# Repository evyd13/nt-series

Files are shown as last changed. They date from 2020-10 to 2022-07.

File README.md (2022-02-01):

# nt-series

## FC660C
Please see the controller for the FC660C [here](https://github.com/evyd13/fc660c-controller).

## About
Replacement PCBs for the FC660m, FC750r, FC980m and FC210TP.

Each of these PCBs have been tested by me, but I cannot guarantee that they work for you.

Use the latest nightly version of KiCAD to open these files. Gerbers and BOM are included for every PCB.

## Stabilizers
All of these PCB designs support PCB mounted stabilizers, but only with a custom made plate, as the stock plate tabs prevent you from putting the plate and PCB together with PCB mounted stabilizers installed.

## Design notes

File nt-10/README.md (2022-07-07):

# nt-10 daughterboard for Leopold keyboards

The nt-10 is a USB-C daughterboard designed to fit the Leopold range of keyboards.  
At the time of writing those are the:

- FC750r
- FC980m
- FC900r

## Installation

Upon removal of the old (probably Mini USB) daughterboard, carefully insert the nt-10 and make sure the USB-C connector fits the cutout in the case. If it does not fit, you can use a small file to increase the cutout size.

### Wiring

The wiring is as follows:

Wiring of nt-10 daughterboard for Leopold keyboard

You might have to swap the wires on some boards, I had to on the 980m. Lift up the tabs using tweezers or a small knife (don't hurt yourself!) and take out the wires, then press the tabs back down and insert the wires in the correct order.

## BOM

| LCSC part # | Description | Value | Package  | Amount |
| --- | --- | ----- | --- | ---:|
| C27834 | Resistor | 5.1k  | 0805 | 2 |
| C261942 | Fuse | | 0805 | 1 |
| C7519 | ESD prot. | | SOT32-6  | 1 |
| C165948 | USB-C conn. | | | 1 |
| C160404 | JST SH 1x4 | | | 1 |
| C392176 | PicoBlade 1x5 | | | 1 |

Use at your own risk.

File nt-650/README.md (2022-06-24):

# nt-650

This is a replacement controller PCB for the FC650M.

nt-650 PCB

## Revisions

### rev1
First revision

## BOM

| LCSC part # | Description | Value | Package  | Amount |
| --- | --- | ----- | --- | ---:|
| C14663 | Capacitor | 0.1uF | 0603 | 4 |
| C19666 | Capacitor | 4.7uF | 0603 | 1 |
| C15849 | Capacitor | 1uF | 0603 | 1 |
| C261942 | Fuse | | 0805 | 1 |
| C124360 | Pin header | 2x16  | TH | 1 |
| C25804 | Resistor | 10K | 0603 | 2 |
| C112161 | MCU | 32U4  | QFN-44 | 1 |
| C341521 | Resonator | 16MHz | SMD | 1 |
| C92584 | Switch | | SMD | 1 |

Use at your own risk.

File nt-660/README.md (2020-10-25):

# nt-660

This is a replacement PCB for the FC660m.

nt-660 PCB

## Revisions

### rev1.1
Adds FC660C bottom row (1.25u - 1.25u - 1.25u - 6u - ...)

### rev1.0
First revision

## BOM

| LCSC part # | Description | Value | Package  | Amount |
| --- | --- | ----- | --- | ---:|
| C128353 | Capacitor | 0.1uF | 0805 | 3 |
| C131056 | Capacitor | 4.7uF | 0805 | 1 |
| C215803 | Capacitor | 1uF | 0805 | 1 |
| C109001 | Diode | | 0805 | 68 |
| C261942 | Fuse | | 0805 | 1 |
| C145778 | Connector | | SMD/TH | 1 |
| C103904 | Resistor | 10K | 0805 | 2 |
| C384174 | Resistor | 1K | 0805 | 1 |
| C325772 | Resistor | 22 | 0805 | 2 |
| C44854 | MCU | 32U4  | QFP-44 | 1 |
| C341521 | Resonator | 16MHz | SMD | 1 |
| C7519 | ESD prot. | | SOT23-6  | 1 |
| C92584 | Switch | | SMD | 1 |

Use at your own risk.

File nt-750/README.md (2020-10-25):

# nt-750

This is a replacement PCB for the FC750r.

nt-750 PCB

## BOM

| LCSC part # | Description | Value | Package  | Amount |
| --- | --- | ----- | --- | ---:|
| C128353 | Capacitor | 0.1uF | 0805 | 4 |
| C131056 | Capacitor | 4.7uF | 0805 | 1 |
| C215803 | Capacitor | 1uF | 0805 | 1 |
| C109001 | Diode | | 0805 | 89 |
| C261942 | Fuse | | 0805 | 1 |
| C157923 | Connector | | TH | 1 |
| C103904 | Resistor | 10K | 0805 | 2 |
| C384174 | Resistor | 1K | 0805 | 1 |
| C325772 | Resistor | 22 | 0805 | 2 |
| C44854 | MCU | 32U4  | QFP-44 | 1 |
| C341521 | Resonator | 16MHz | SMD | 1 |
| C7519 | ESD prot. | | SOT23-6  | 1 |
| C92584 | Switch | | SMD | 1 |

Use at your own risk.

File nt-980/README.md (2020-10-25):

# nt-980

This is a replacement PCB for the FC980m.

nt-980 PCB

## BOM

| LCSC part # | Description | Value | Package  | Amount |
| --- | --- | ----- | --- | ---:|
| C128353 | Capacitor | 0.1uF | 0805 | 4 |
| C131056 | Capacitor | 4.7uF | 0805 | 1 |
| C215803 | Capacitor | 1uF | 0805 | 1 |
| C109001 | Diode | | 0805 | 100 |
| C261942 | Fuse | | 0805 | 1 |
| C64617 | Female header | | SMD | 1 |
| C103904 | Resistor | 10K | 0805 | 2 |
| C384174 | Resistor | 1K | 0805 | 3 |
| C325772 | Resistor | 22 | 0805 | 2 |
| C44854 | MCU | 32U4  | QFP-44 | 1 |
| C341521 | Resonator | 16MHz | SMD | 1 |
| C7519 | ESD prot. | | SOT23-6  | 1 |
| C92584 | Switch | | SMD | 1 |

Use at your own risk.

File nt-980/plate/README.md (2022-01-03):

Plate files for FC980m.  

**This CANNOT be used with the stock FC980m PCB!** (Stock PCB uses plate stabs)

The KLE files can be used with the Ai03 plate generator to get the proper cut out possition of the switches (the edge cuts would need to be manually added to the file): https://kbplate.ai03.com/

Note: Only confirmed Alternate ANSI Layout <alternateLayouts.ANSI.dxf>, the other layout files "should" work but use at your own risk.

Alternate Layout ANSI <alternateLayouts.ANSI.dxf>
AlternateLayout

Alternate Layout ANSI/ISO <alternateLayouts.ISO.dxf>
AlternateLayout

Standard Layout ANSI <standardLayout.ANSI.dxf>
StandardLayout

Standard Layout ISO <standardLayout.ISO.dxf>
StandardLayoutISO

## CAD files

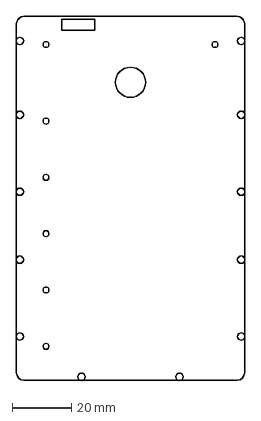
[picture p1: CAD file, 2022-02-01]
nt-210/pcb-outline.dxf
77.3 x 123.2 mm

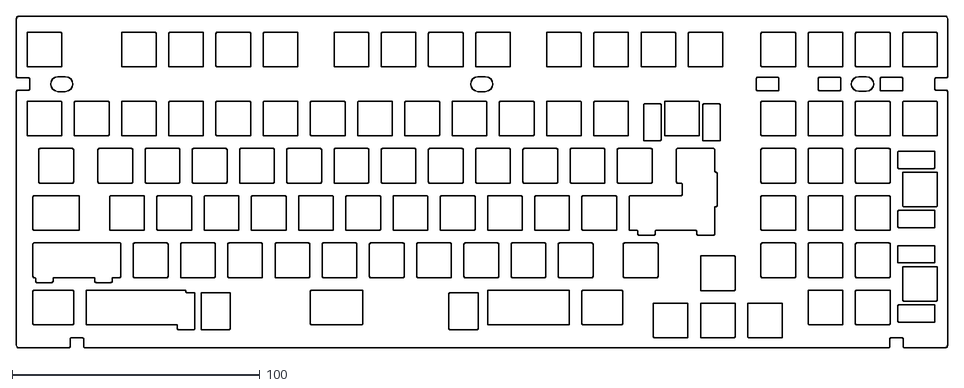
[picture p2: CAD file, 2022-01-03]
nt-980/plate/alternateLayouts.ISO.dxf
375.6 x 133.8

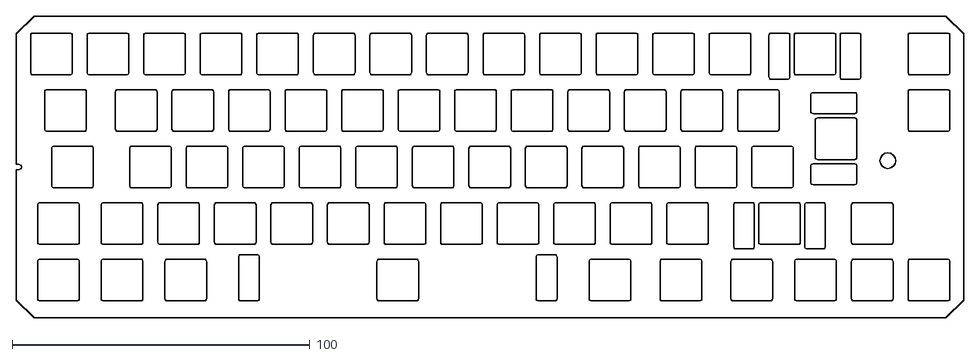
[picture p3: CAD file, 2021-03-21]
nt-660/plate/iso.dxf
318.5 x 101.4

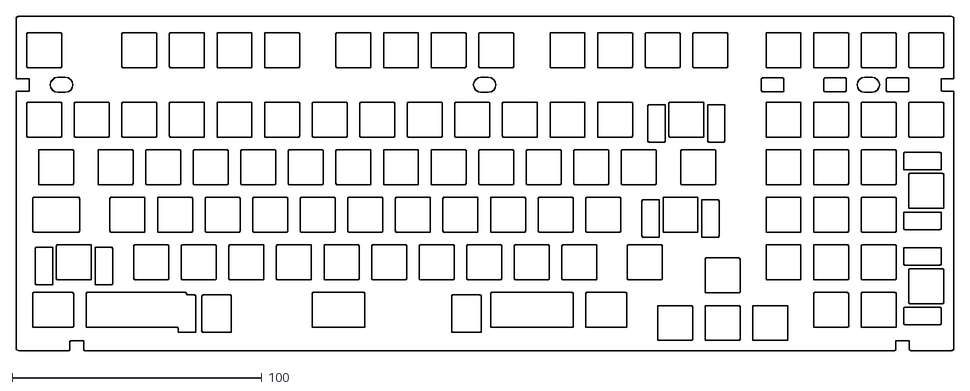
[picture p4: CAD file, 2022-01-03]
nt-980/plate/alternateLayouts.ANSI.dxf
375.6 x 133.8

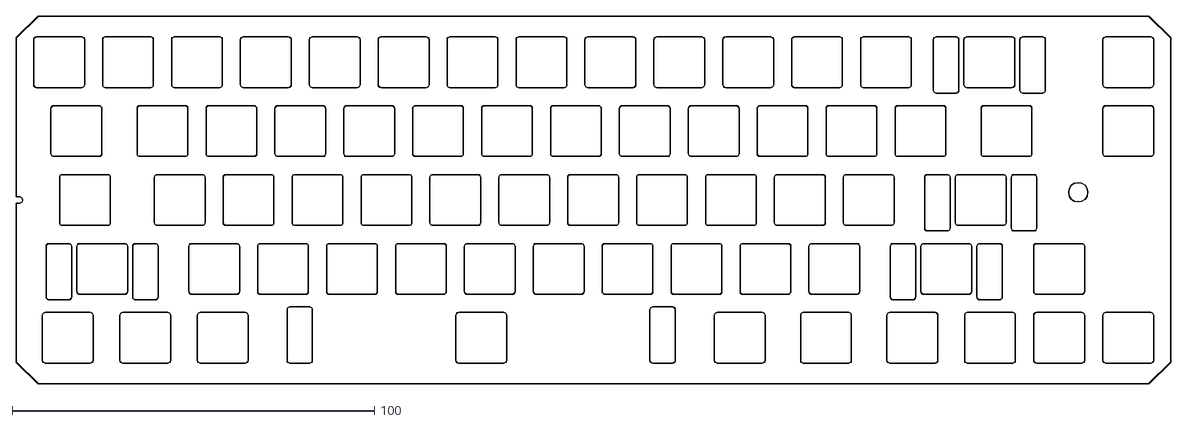
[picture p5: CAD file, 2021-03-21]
nt-660/plate/ansi.dxf
318.5 x 101.4

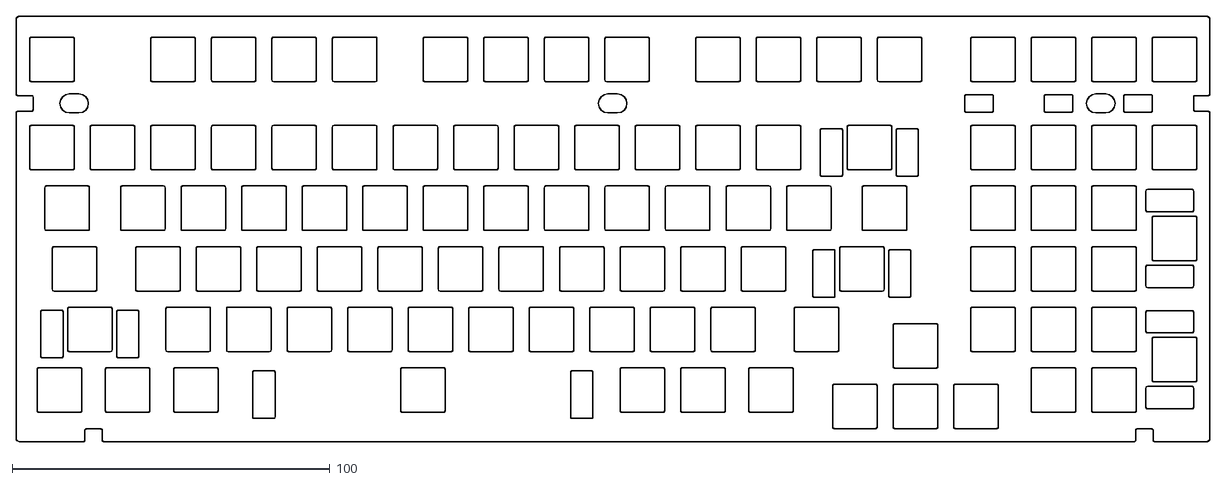
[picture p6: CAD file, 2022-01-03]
nt-980/plate/standardLayout.ANSI.dxf
375.6 x 133.8

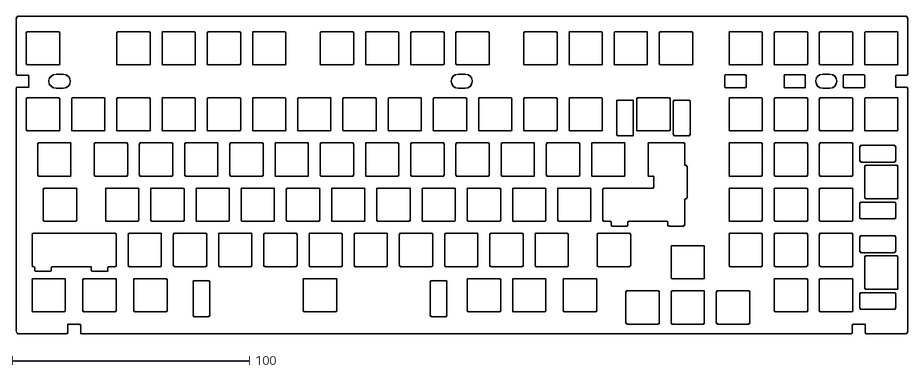
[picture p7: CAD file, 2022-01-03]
nt-980/plate/standardLayout.ISO.dxf
375.6 x 133.8

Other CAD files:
nt-660/plate/plate.FCStd

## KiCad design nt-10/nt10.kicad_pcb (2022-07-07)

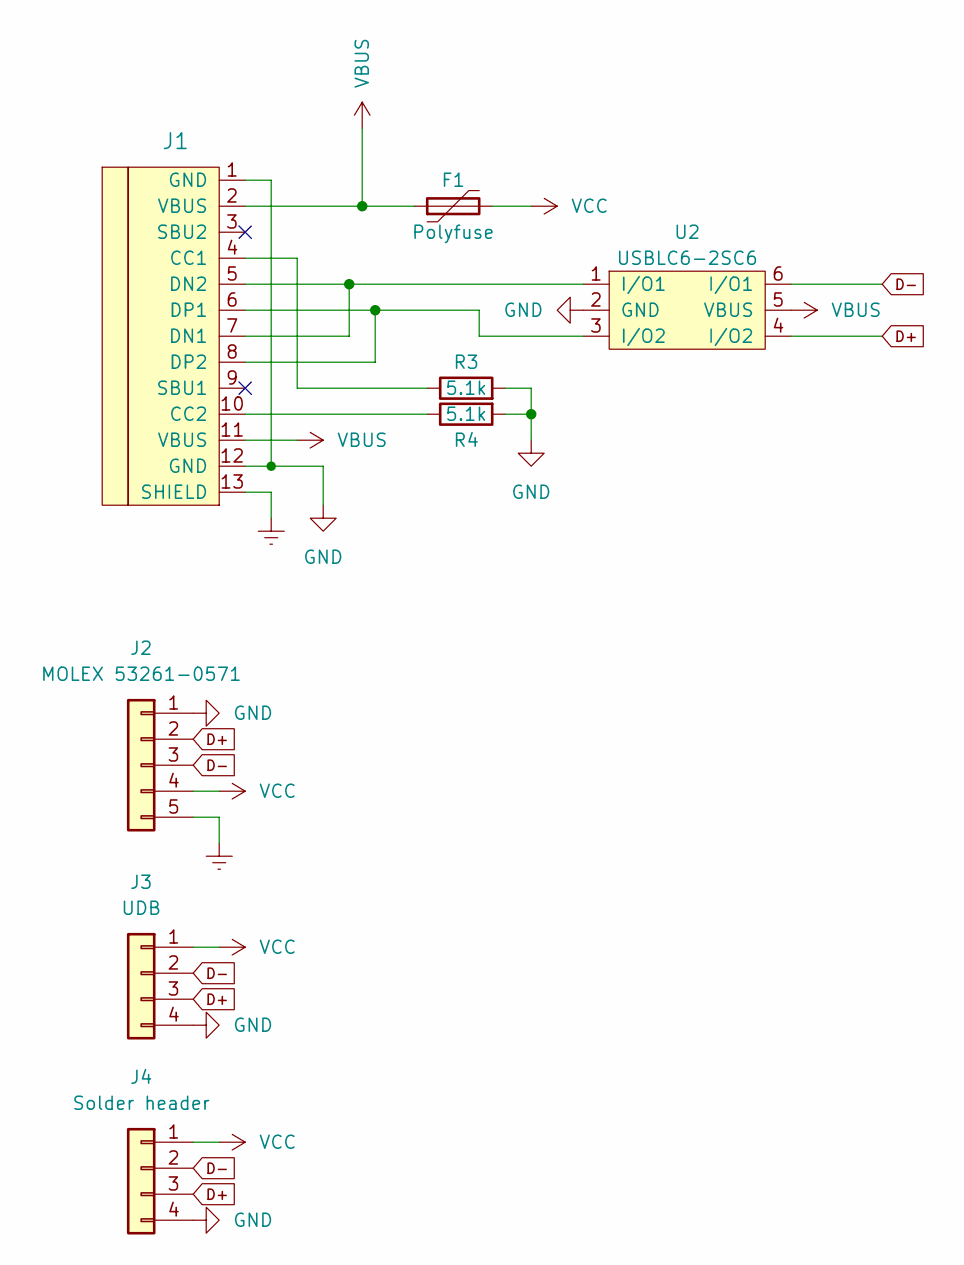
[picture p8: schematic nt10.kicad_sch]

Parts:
F1: Polyfuse; F_0805; LCSC Part C261942
J1: HRO-TYPE-C-31-M-12; LCSC Part C165948
J2: MOLEX 53261-0571; Molex_PicoBlade_53261-0571_1x05-1MP_P1.25mm_Horizontal; LCSC Part C392176
J3: UDB; CONN_JST_SH_SM04B-SRSS-TB_1x04-1MP_P1.00mm_Horizontal; LCSC Part C160404
J4: Solder header; 01x04-solder-header
R3, R4: 5.1k; R_0805; LCSC Part C27834
U2: USBLC6-2SC6; LCSC Part C7519

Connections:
D+: J2.2, J3.3, J4.3, U2.4 (I/O2)
D-: J2.3, J3.2, J4.2, U2.6 (I/O1)
Earth: J1.13 (SHIELD), J2.5
GND: J1.1 (GND), J1.12 (GND), J2.1, J3.4, J4.4, R3.2, R4.2, U2.2 (GND)
unnamed: J1.4 (CC1), R3.1
unnamed: J1.5 (DN2), J1.7 (DN1), U2.1 (I/O1)
unnamed: J1.6 (DP1), J1.8 (DP2), U2.3 (I/O2)
unnamed: J1.10 (CC2), R4.1
VBUS: F1.1, J1.2 (VBUS), J1.11 (VBUS), U2.5 (VBUS)
VCC: F1.2, J2.4, J3.1, J4.1

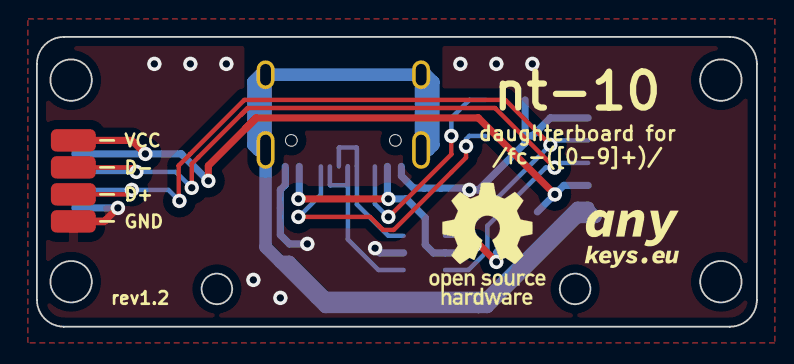
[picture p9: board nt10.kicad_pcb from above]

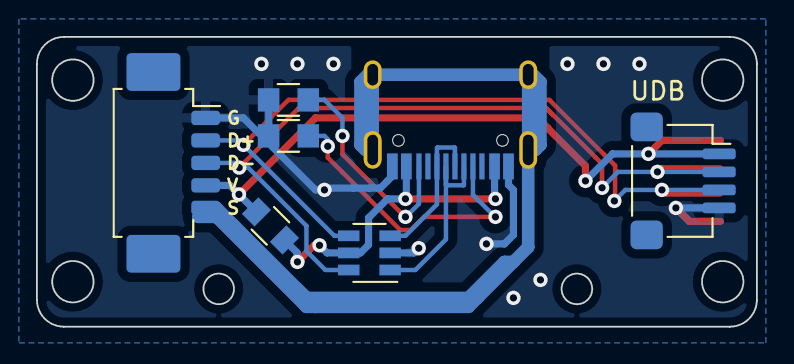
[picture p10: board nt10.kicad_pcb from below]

Board: 2 copper layers, 40.0 x 16.1 mm, 8 parts (7 on the bottom side), 10 nets.

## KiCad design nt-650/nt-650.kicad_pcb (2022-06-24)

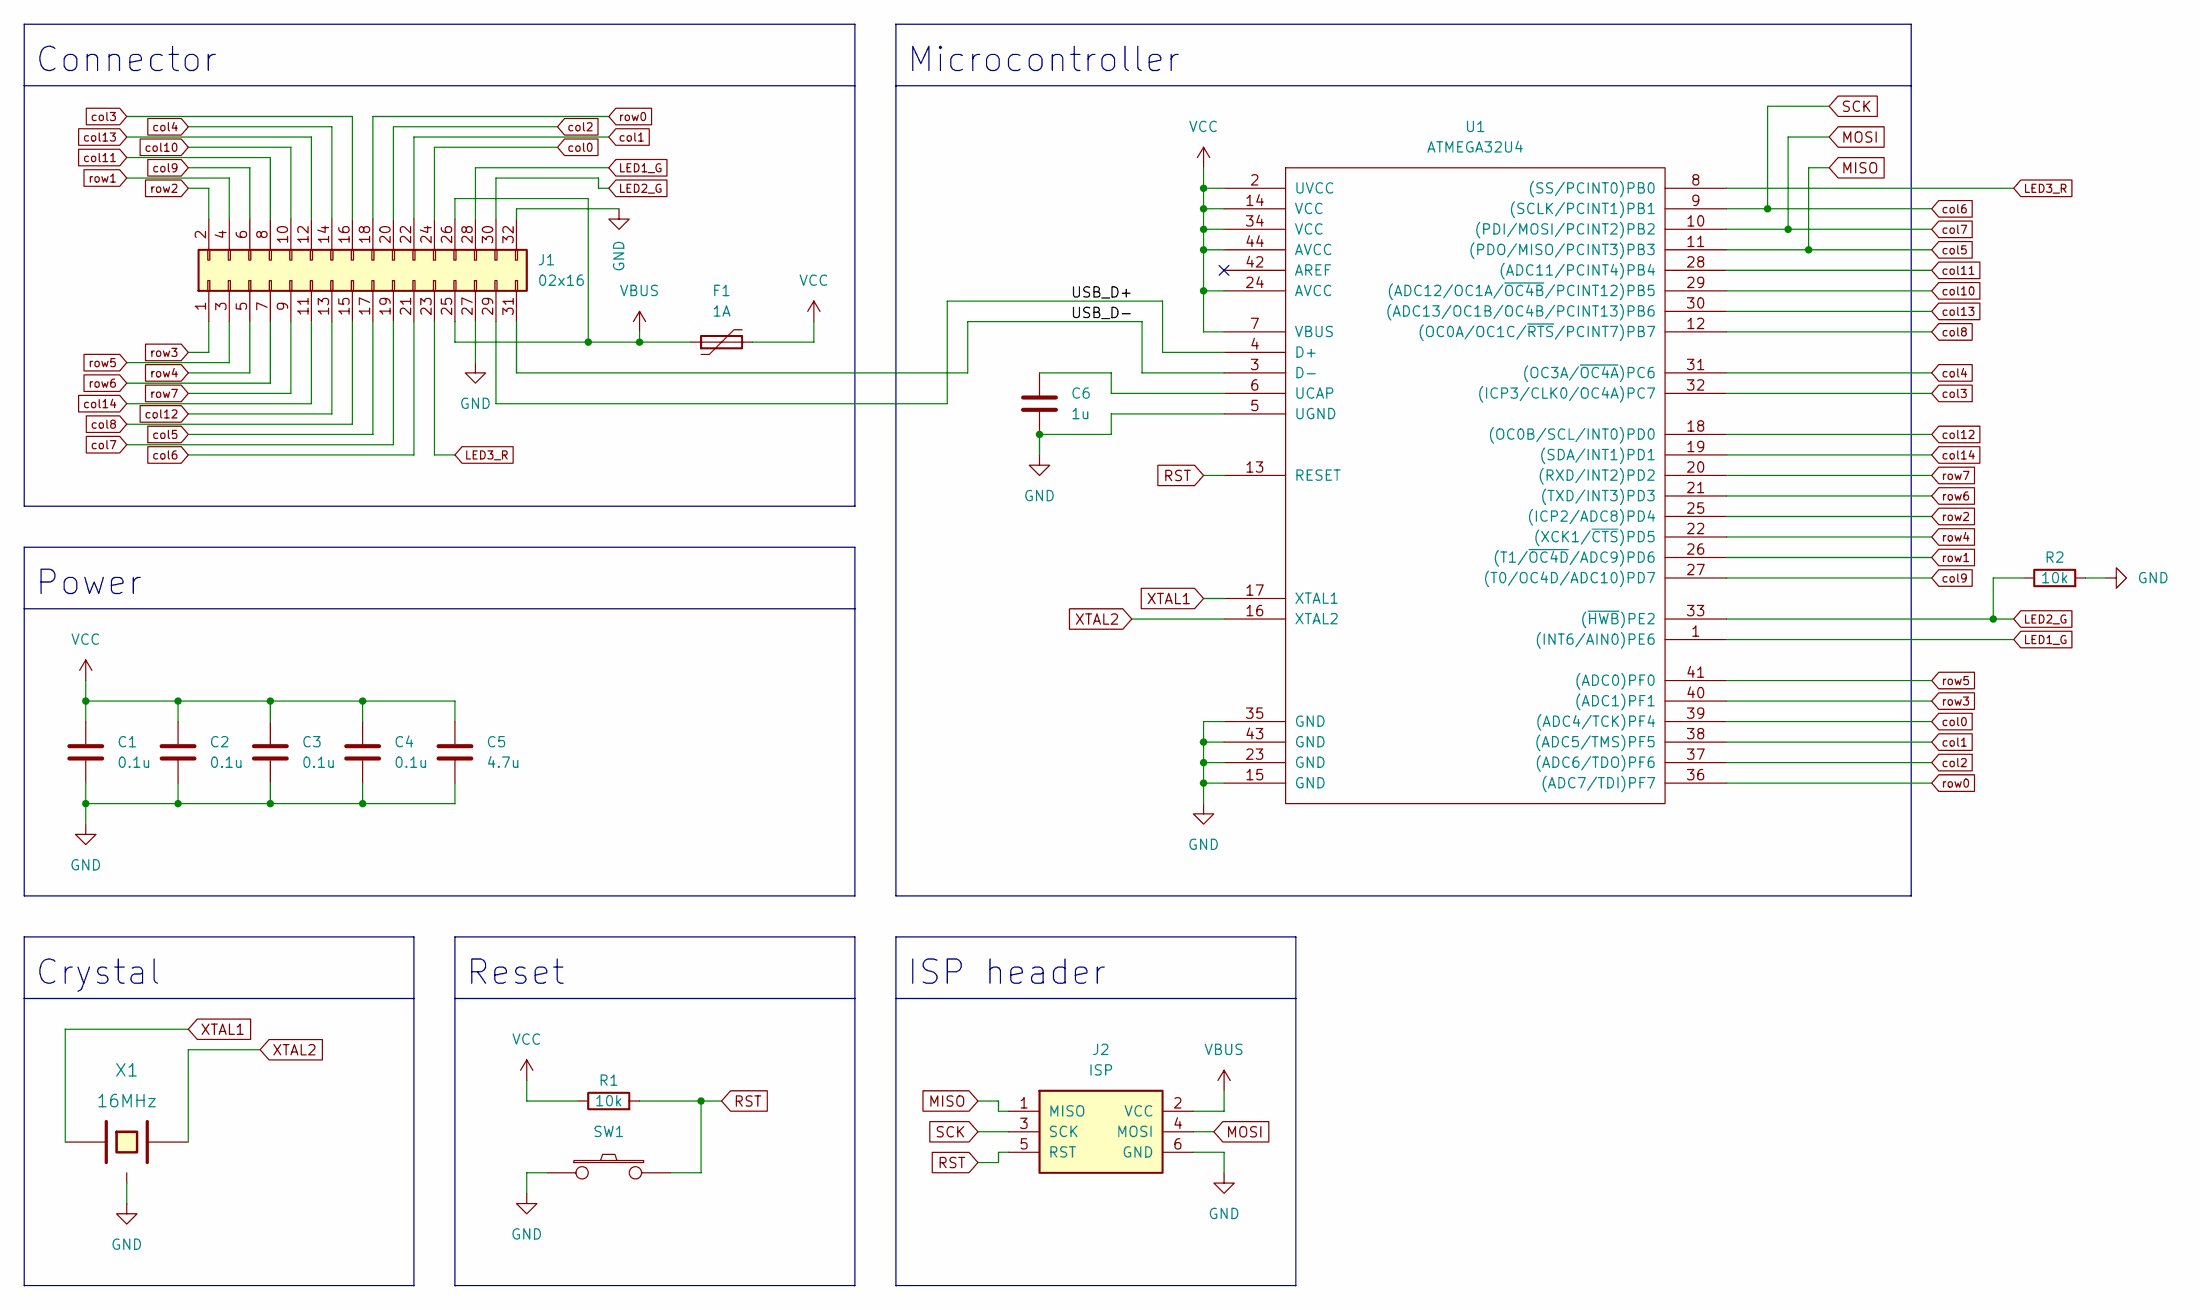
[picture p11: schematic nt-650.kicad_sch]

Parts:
C1, C2, C3, C4: 0.1u; C_0603; Part number CC0603KRX7R9BB104; LCSC Part C14663
C5: 4.7u; C_0603; Part number CL10A475KO8NNNC; LCSC Part C19666
C6: 1u; C_0603; Part number CL10A105KB8NNNC; LCSC Part C15849
F1: 1A; R_0805; Part number TLC-PSMD050; LCSC Part C261942
J1: 02x16; PinHeader_2x16_P2.00mm_Vertical; JLCPCB BOM 0
J2: ISP; CONN_isp_standard; JLCPCB BOM 0
R1, R2: 10k; R_0603; Part number 0603WAF1002T5E; LCSC Part C25804
SW1: SW_PUSH; SWITCH_SPST_TL3342_W_JUMP; Part number TS-1187A-B-A-B; LCSC Part C318884
U1: ATMEGA32U4; MCU_ATMEGA32U4-MU; Part number ATMEGA32U4-MU; LCSC Part C112161
X1: 16MHz; XTAL_SMD_Murata_CSTxExxV-3Pin_3.0x1.1mm; Part number CSTNE16M0V530000R0; LCSC Part C341521

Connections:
/USB_D+: J1.29, U1.4 (D+)
/USB_D-: J1.31, U1.3 (D-)
GND: C1.2, C2.2, C3.2, C4.2, C5.2, C6.2, J1.27, J1.32, J2.6 (GND), R2.2, SW1.1, U1.5 (UGND), U1.15 (GND), U1.23 (GND), U1.35 (GND), U1.43 (GND), X1.3
LED1_G: J1.28, U1.1 ((INT6/AIN0)PE6)
LED2_G: J1.30, R2.1, U1.33 ((~HWB)PE2)
LED3_R: J1.23, U1.8 ((SS/PCINT0)PB0)
MISO: J1.17, J2.1 (MISO), U1.11 ((PDO/MISO/PCINT3)PB3)
MOSI: J1.19, J2.4 (MOSI), U1.10 ((PDI/MOSI/PCINT2)PB2)
unnamed: C6.1, U1.6 (UCAP)
RST: J2.5 (RST), R1.2, SW1.2, U1.13 (RESET)
SCK: J1.21, J2.3 (SCK), U1.9 ((SCLK/PCINT1)PB1)
VBUS: F1.1, J1.25, J1.26, J2.2 (VCC)
VCC: C1.1, C2.1, C3.1, C4.1, C5.1, F1.2, R1.1, U1.2 (UVCC), U1.7 (VBUS), U1.14 (VCC), U1.24 (AVCC), U1.34 (VCC), U1.44 (AVCC)
XTAL1: U1.17 (XTAL1), X1.1
XTAL2: U1.16 (XTAL2), X1.2
col0: J1.24, U1.39 ((ADC4/TCK)PF4)
col1: J1.22, U1.38 ((ADC5/TMS)PF5)
col2: J1.20, U1.37 ((ADC6/TDO)PF6)
col3: J1.16, U1.32 ((ICP3/CLK0/OC4A)PC7)
col4: J1.14, U1.31 ((OC3A/~OC4A)PC6)
col8: J1.15, U1.12 ((OC0A/OC1C/~RTS/PCINT7)PB7)
col9: J1.6, U1.27 ((T0/OC4D/ADC10)PD7)
col10: J1.10, U1.29 ((ADC12/OC1A/~OC4B/PCINT12)PB5)
col11: J1.8, U1.28 ((ADC11/PCINT4)PB4)
col12: J1.13, U1.18 ((OC0B/SCL/INT0)PD0)
col13: J1.12, U1.30 ((ADC13/OC1B/OC4B/PCINT13)PB6)
col14: J1.11, U1.19 ((SDA/INT1)PD1)
row0: J1.18, U1.36 ((ADC7/TDI)PF7)
row1: J1.4, U1.26 ((T1/~OC4D/ADC9)PD6)
row2: J1.2, U1.25 ((ICP2/ADC8)PD4)
row3: J1.1, U1.40 ((ADC1)PF1)
row4: J1.5, U1.22 ((XCK1/~CTS)PD5)
row5: J1.3, U1.41 ((ADC0)PF0)
row6: J1.7, U1.21 ((TXD/INT3)PD3)
row7: J1.9, U1.20 ((RXD/INT2)PD2)

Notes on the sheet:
Microcontroller
Power
Reset
ISP header
Crystal
Connector

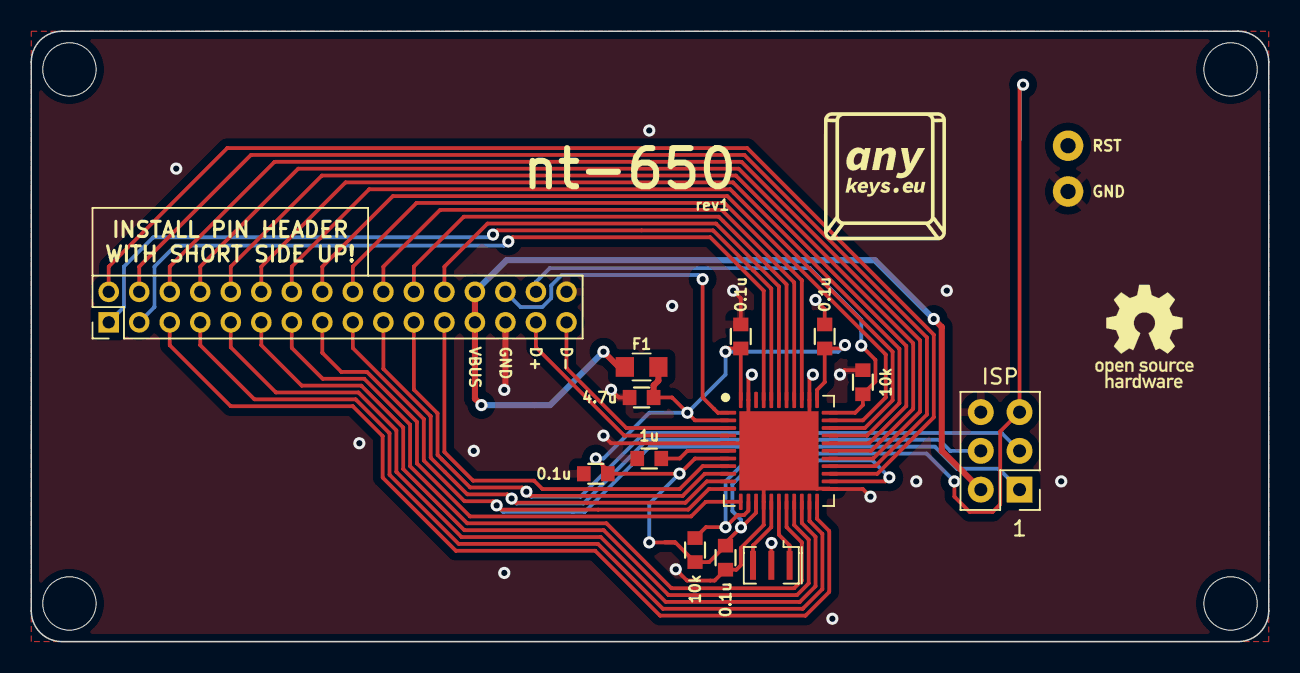
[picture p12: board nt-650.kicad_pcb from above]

Board: 2 copper layers, 81.1 x 40.0 mm, 14 parts (1 on the bottom side), 35 nets.

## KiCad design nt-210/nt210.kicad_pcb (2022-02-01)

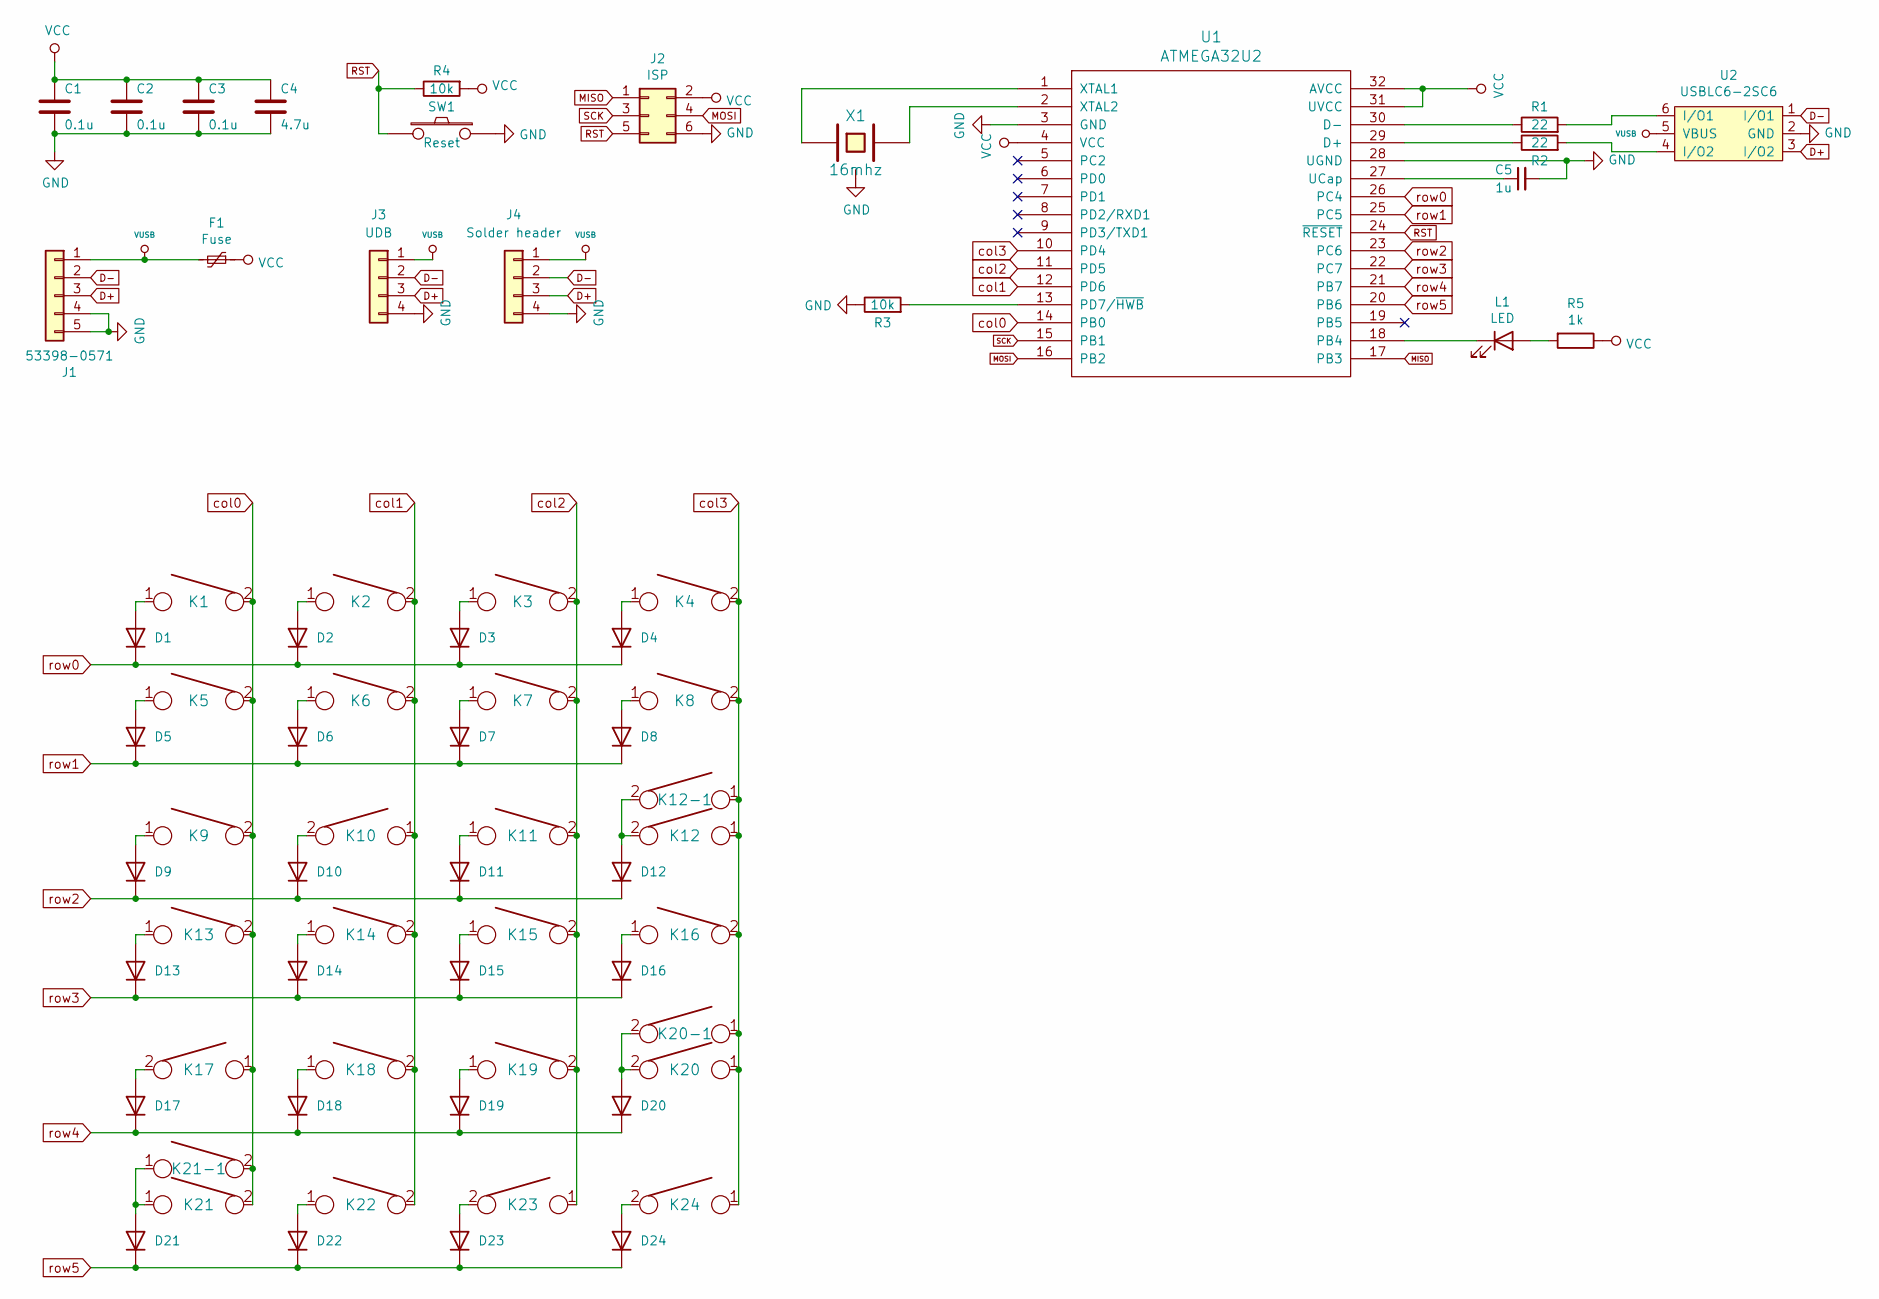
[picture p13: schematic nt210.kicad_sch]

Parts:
C1, C2, C3: 0.1u; C_0603
C4: 4.7u; C_0603
C5: 1u; C_0603
D1, D2, D3, D4, D5, D6, D7, D8, D9, D10, D11, D12, D13, D14, D15, D16, D17, D18, D19, D20, D21, D22, D23, D24: D; D_0805
F1: Fuse; F_0805
J1: 53398-0571; Molex-PicoBlade-533980571
J2: ISP; isp_standard
J3: UDB; JST_SH_SM04B-SRSS-TB_1x04-1MP_P1.00mm_Horizontal
J4: Solder header; solder_header
K1, K2, K3, K4, K5, K6, K7, K8, K9, K10, K11, K12-1, K13, K14, K15, K16, K17, K18, K19, K20-1, K21-1, K22, K23, K24: KEYSW; CHERRY_PLATE_100H
K12, K20: KEYSW; CHERRY_PLATE_200H_V
K21: KEYSW; CHERRY_PLATE_200H
L1: LED; CHERRY_MX_LED_neo
R1, R2: 22; R_0603
R3, R4: 10k; R_0603
R5: 1k; R_0603
SW1: Reset; SW_SPST_TL3342
U1: ATMEGA32U2
U2: USBLC6-2SC6
X1: 16mhz; Resonator_SMD_muRata_CSTNExxV-3Pin-p1.2

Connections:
D+: J1.3, J3.3, J4.3, U2.3 (I/O2)
D-: J1.2, J3.2, J4.2, U2.1 (I/O1)
GND: C1.2, C2.2, C3.2, C4.2, C5.2, J1.4, J1.5, J2.6, J3.4, J4.4, R3.1, SW1.1, U1.3 (GND), U1.28 (UGND), U2.2 (GND), X1.3
MISO: J2.1, U1.17 (PB3)
MOSI: J2.4, U1.16 (PB2)
unnamed: C5.1, U1.27 (UCap)
unnamed: D1.2 (A), K1.1
unnamed: D2.2 (A), K2.1
unnamed: D3.2 (A), K3.1
unnamed: D4.2 (A), K4.1
unnamed: D5.2 (A), K5.1
unnamed: D6.2 (A), K6.1
unnamed: D7.2 (A), K7.1
unnamed: D8.2 (A), K8.1
unnamed: D9.2 (A), K9.1
unnamed: D10.2 (A), K10.2
unnamed: D11.2 (A), K11.1
unnamed: D12.2 (A), K12.2, K12-1.2
unnamed: D13.2 (A), K13.1
unnamed: D14.2 (A), K14.1
unnamed: D15.2 (A), K15.1
unnamed: D16.2 (A), K16.1
unnamed: D17.2 (A), K17.2
unnamed: D18.2 (A), K18.1
unnamed: D19.2 (A), K19.1
unnamed: D20.2 (A), K20.2, K20-1.2
unnamed: D21.2 (A), K21.1, K21-1.1
unnamed: D22.2 (A), K22.1
unnamed: D23.2 (A), K23.2
unnamed: D24.2 (A), K24.2
unnamed: L1.1 (K), U1.18 (PB4)
unnamed: L1.2 (A), R5.2
unnamed: R1.1, U1.30 (D-)
unnamed: R1.2, U2.6 (I/O1)
unnamed: R2.1, U1.29 (D+)
unnamed: R2.2, U2.4 (I/O2)
unnamed: R3.2, U1.13 (PD7/~HWB)
unnamed: U1.1 (XTAL1), X1.1
unnamed: U1.2 (XTAL2), X1.2
RST: J2.5, R4.1, SW1.2, U1.24 (~RESET)
SCK: J2.3, U1.15 (PB1)
VCC: C1.1, C2.1, C3.1, C4.1, F1.1, J2.2, R4.2, R5.1, U1.4 (VCC), U1.31 (UVCC), U1.32 (AVCC)
VUSB: F1.2, J1.1, J3.1, J4.1, U2.5 (VBUS)
col0: K1.2, K5.2, K9.2, K13.2, K17.1, K21.2, K21-1.2, U1.14 (PB0)
col1: K2.2, K6.2, K10.1, K14.2, K18.2, K22.2, U1.12 (PD6)
col2: K3.2, K7.2, K11.2, K15.2, K19.2, K23.1, U1.11 (PD5)
col3: K4.2, K8.2, K12.1, K12-1.1, K16.2, K20.1, K20-1.1, K24.1, U1.10 (PD4)
row0: D1.1 (K), D2.1 (K), D3.1 (K), D4.1 (K), U1.26 (PC4)
row1: D5.1 (K), D6.1 (K), D7.1 (K), D8.1 (K), U1.25 (PC5)
row2: D9.1 (K), D10.1 (K), D11.1 (K), D12.1 (K), U1.23 (PC6)
row3: D13.1 (K), D14.1 (K), D15.1 (K), D16.1 (K), U1.22 (PC7)
row4: D17.1 (K), D18.1 (K), D19.1 (K), D20.1 (K), U1.21 (PB7)
row5: D21.1 (K), D22.1 (K), D23.1 (K), D24.1 (K), U1.20 (PB6)

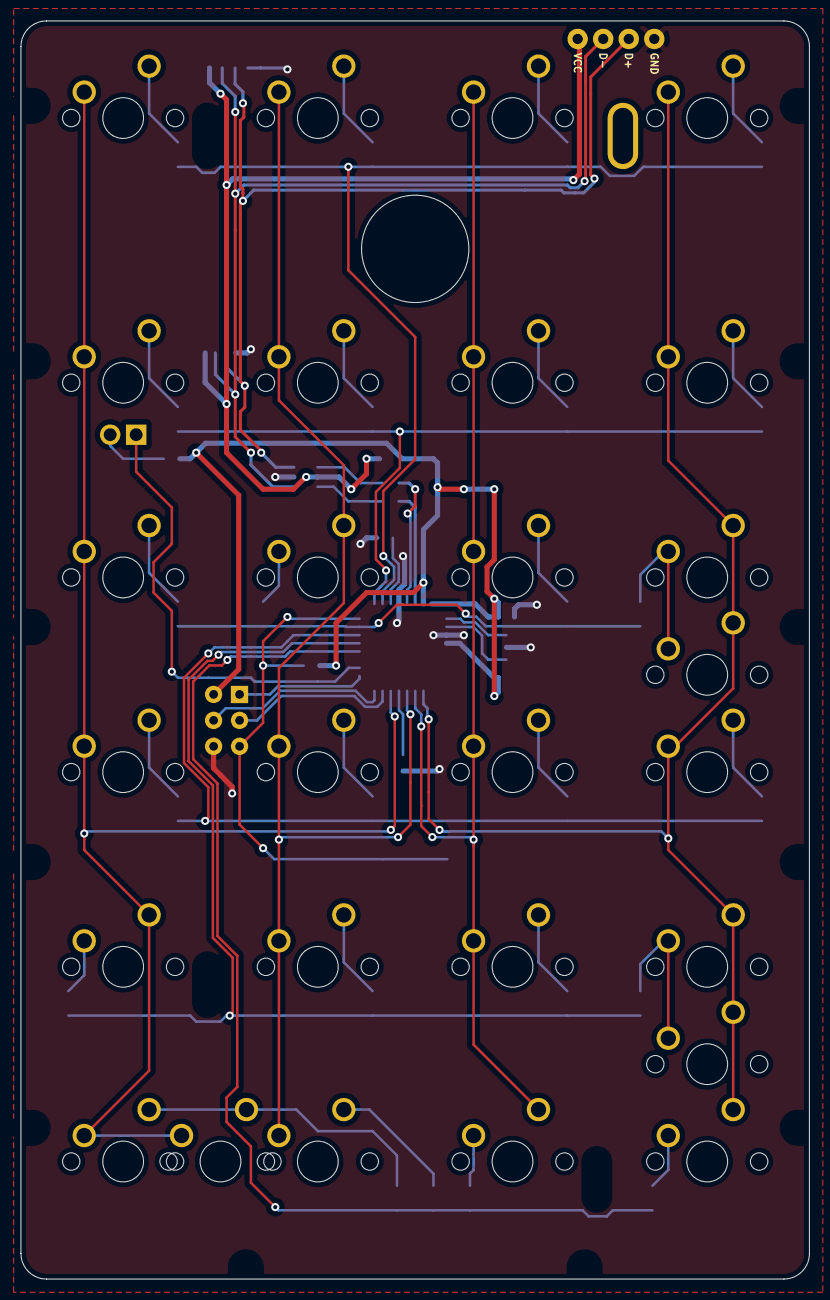
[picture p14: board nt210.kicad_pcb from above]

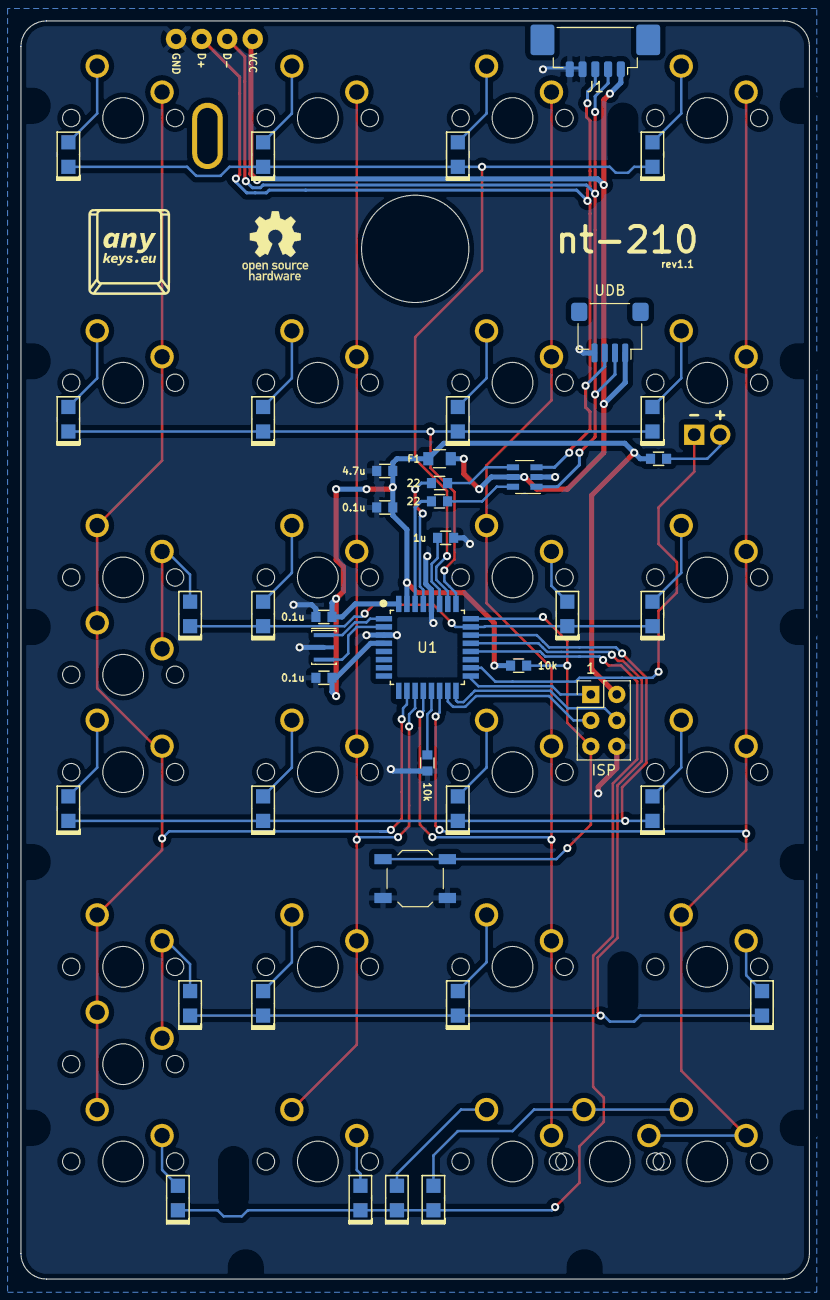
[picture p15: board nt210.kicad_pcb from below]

Board: 2 copper layers, 77.2 x 123.1 mm, 71 parts (42 on the bottom side), 53 nets.

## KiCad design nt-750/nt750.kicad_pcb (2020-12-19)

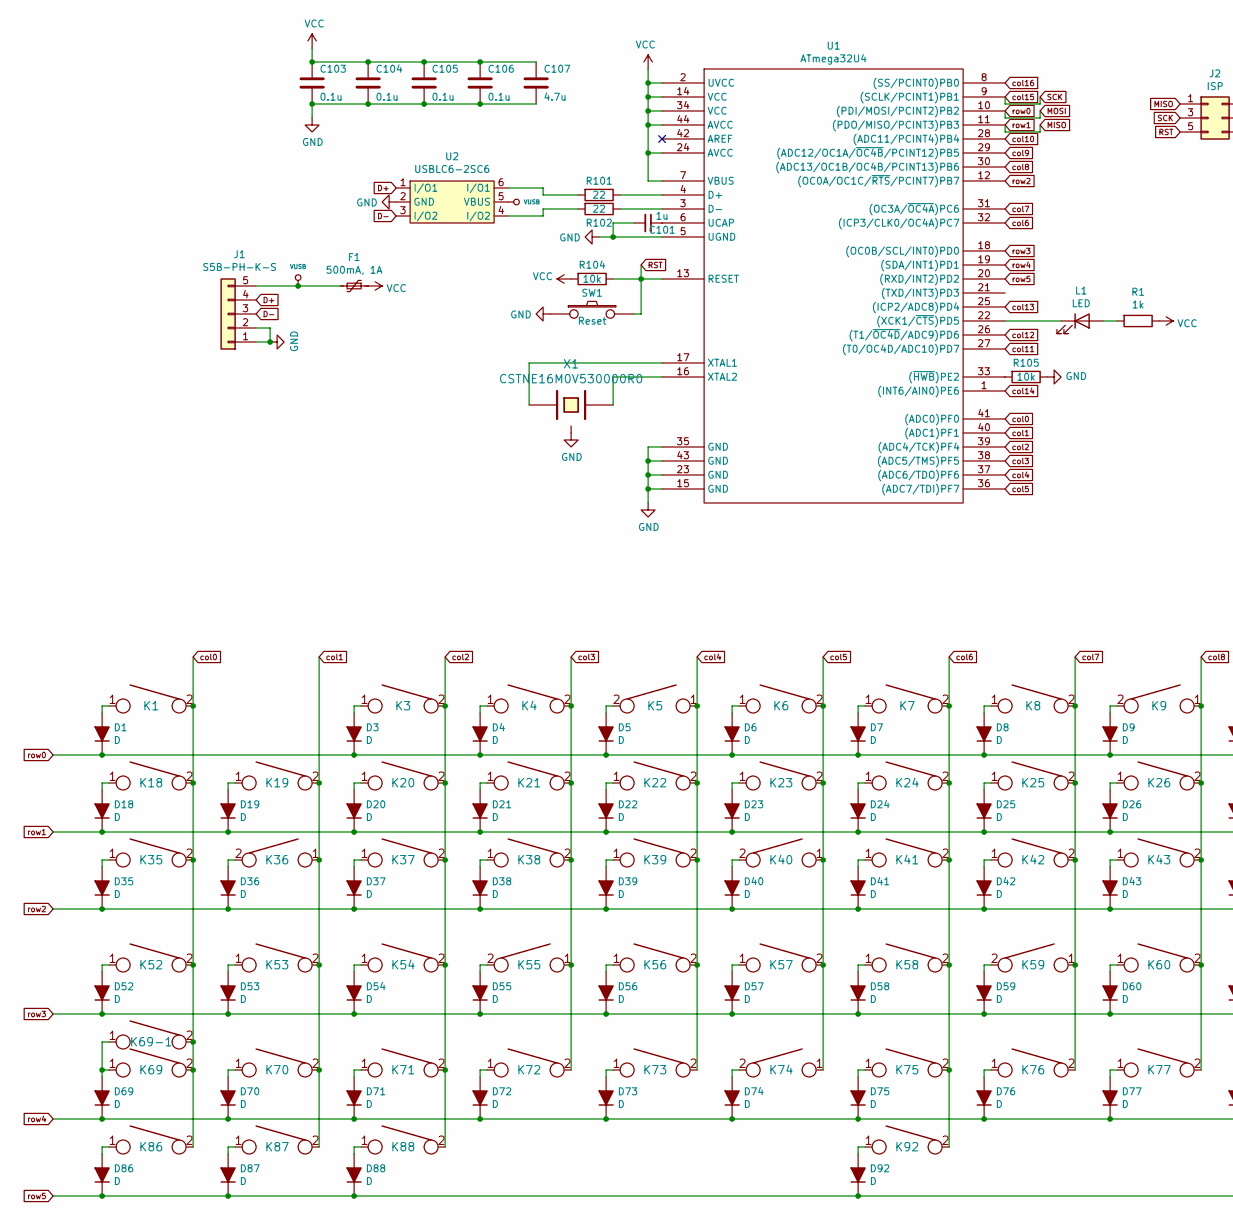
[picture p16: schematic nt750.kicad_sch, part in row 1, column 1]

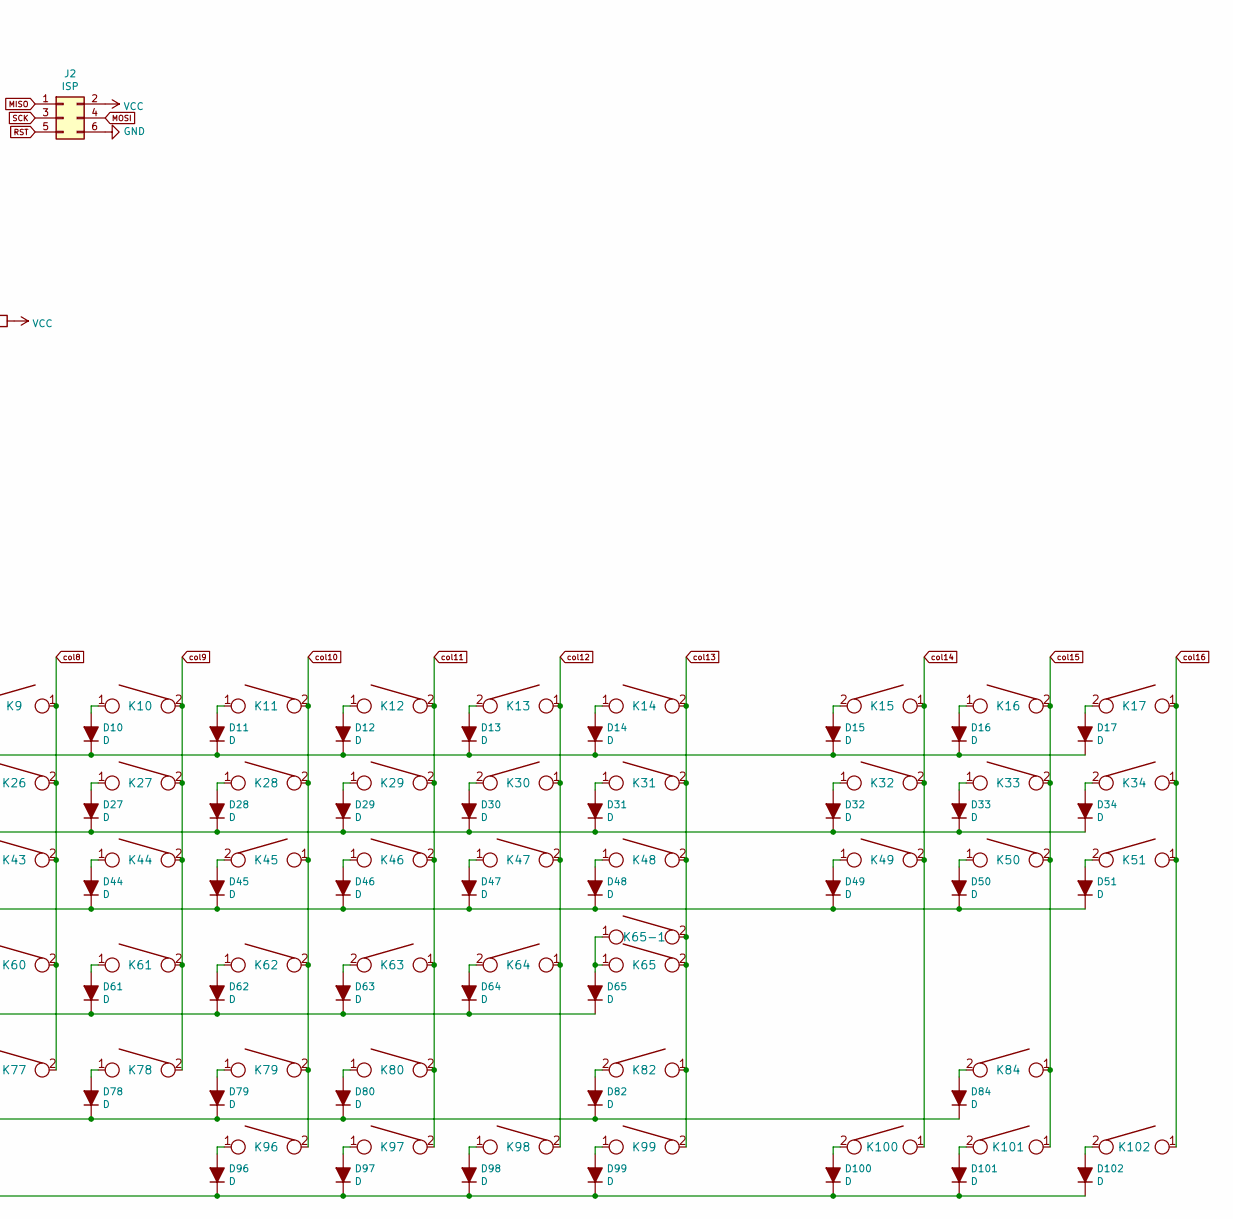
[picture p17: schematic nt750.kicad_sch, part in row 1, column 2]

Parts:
C101: 1u; C_0805
C103, C104, C105, C106: 0.1u; C_0805
C107: 4.7u; C_0805
D1, D3, D4, D5, D6, D7, D8, D9, D10, D11, D12, D13, D14, D15, D16, D17, D18, D19, D20, D21, D22, D23, D24, D25, D26, D27, D28, D29, D30, D31, D32, D33, D34, D35, D36, D37, D38, D39, D40, D41, D42, D43, D44, D45, D46, D47, D48, D49, D50, D51, D52, D53, D54, D55, D56, D57, D58, D59, D60, D61, D62, D63, D64, D65, D69, D70, D71, D72, D73, D74, D75, D76, D77, D78, D79, D80, D82, D84, D86, D87, D88, D92, D96, D97, D98, D99, D100, D101, D102: D; D_0805
F1: 500mA, 1A; R_0805
J1: S5B-PH-K-S; JST_PH_S5B-PH-K_1x05_P2.00mm_Horizontal
J2: ISP; isp_standard
K1, K3, K4, K5, K6, K7, K8, K9, K10, K11, K12, K13, K14, K15, K16, K17, K18, K19, K20, K21, K22, K23, K24, K25, K26, K27, K28, K29, K30, K32, K33, K34, K36, K37, K38, K39, K40, K41, K42, K43, K44, K45, K46, K47, K49, K50, K51, K53, K54, K55, K56, K57, K58, K59, K60, K61, K62, K63, K64, K70, K71, K72, K73, K74, K75, K76, K77, K78, K79, K80, K84, K100, K101, K102: KEYSW; CHERRY_PLATE_100H
K31: KEYSW; CHERRY_PCB_200H
K35, K48: KEYSW; CHERRY_PLATE_150H
K52: KEYSW; CHERRY_PLATE_175H
K65, K69: KEYSW; CHERRY_PCB_225H
K65-1: KEYSW; CHERRY_PCB_200H_V
K69-1, K86, K87, K88, K96, K97, K98, K99: KEYSW; CHERRY_PLATE_125H
K82: KEYSW; CHERRY_PCB_275H
K92: KEYSW; CHERRY_PCB_625H_F
L1: LED; CHERRY_MX_LED
R1: 1k; R_0805
R101, R102: 22; R_0805
R104, R105: 10k; R_0805
SW1: Reset; SW_SPST_TL3342
U1: ATmega32U4; ATMEGA32U4
U2: USBLC6-2SC6
X1: CSTNE16M0V530000R0; Resonator_SMD_muRata_CSTNExxV-3Pin-p1.2

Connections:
D+: J1.4, U2.1 (I/O1)
D-: J1.3, U2.3 (I/O2)
GND: C101.2, C103.2, C104.2, C105.2, C106.2, C107.2, J1.1, J1.2, J2.6, R105.1, SW1.1, U1.5 (UGND), U1.15 (GND), U1.23 (GND), U1.35 (GND), U1.43 (GND), U2.2 (GND), X1.3
MISO: D18.1 (K), D19.1 (K), D20.1 (K), D21.1 (K), D22.1 (K), D23.1 (K), D24.1 (K), D25.1 (K), D26.1 (K), D27.1 (K), D28.1 (K), D29.1 (K), D30.1 (K), D31.1 (K), D32.1 (K), D33.1 (K), D34.1 (K), J2.1, U1.11 ((PDO/MISO/PCINT3)PB3)
MOSI: D1.1 (K), D3.1 (K), D4.1 (K), D5.1 (K), D6.1 (K), D7.1 (K), D8.1 (K), D9.1 (K), D10.1 (K), D11.1 (K), D12.1 (K), D13.1 (K), D14.1 (K), D15.1 (K), D16.1 (K), D17.1 (K), J2.4, U1.10 ((PDI/MOSI/PCINT2)PB2)
unnamed: C101.1, U1.6 (UCAP)
unnamed: D1.2 (A), K1.1
unnamed: D3.2 (A), K3.1
unnamed: D4.2 (A), K4.1
unnamed: D5.2 (A), K5.2
unnamed: D6.2 (A), K6.1
unnamed: D7.2 (A), K7.1
unnamed: D8.2 (A), K8.1
unnamed: D9.2 (A), K9.2
unnamed: D10.2 (A), K10.1
unnamed: D11.2 (A), K11.1
unnamed: D12.2 (A), K12.1
unnamed: D13.2 (A), K13.2
unnamed: D14.2 (A), K14.1
unnamed: D15.2 (A), K15.2
unnamed: D16.2 (A), K16.1
unnamed: D17.2 (A), K17.2
unnamed: D18.2 (A), K18.1
unnamed: D19.2 (A), K19.1
unnamed: D20.2 (A), K20.1
unnamed: D21.2 (A), K21.1
unnamed: D22.2 (A), K22.1
unnamed: D23.2 (A), K23.1
unnamed: D24.2 (A), K24.1
unnamed: D25.2 (A), K25.1
unnamed: D26.2 (A), K26.1
unnamed: D27.2 (A), K27.1
unnamed: D28.2 (A), K28.1
unnamed: D29.2 (A), K29.1
unnamed: D30.2 (A), K30.2
unnamed: D31.2 (A), K31.1
unnamed: D32.2 (A), K32.1
unnamed: D33.2 (A), K33.1
unnamed: D34.2 (A), K34.2
unnamed: D35.2 (A), K35.1
unnamed: D36.2 (A), K36.2
unnamed: D37.2 (A), K37.1
unnamed: D38.2 (A), K38.1
unnamed: D39.2 (A), K39.1
unnamed: D40.2 (A), K40.2
unnamed: D41.2 (A), K41.1
unnamed: D42.2 (A), K42.1
unnamed: D43.2 (A), K43.1
unnamed: D44.2 (A), K44.1
unnamed: D45.2 (A), K45.2
unnamed: D46.2 (A), K46.1
unnamed: D47.2 (A), K47.1
unnamed: D48.2 (A), K48.1
unnamed: D49.2 (A), K49.1
unnamed: D50.2 (A), K50.1
unnamed: D51.2 (A), K51.2
unnamed: D52.2 (A), K52.1
unnamed: D53.2 (A), K53.1
unnamed: D54.2 (A), K54.1
unnamed: D55.2 (A), K55.2
unnamed: D56.2 (A), K56.1
unnamed: D57.2 (A), K57.1
unnamed: D58.2 (A), K58.1
unnamed: D59.2 (A), K59.2
unnamed: D60.2 (A), K60.1
unnamed: D61.2 (A), K61.1
unnamed: D62.2 (A), K62.1
unnamed: D63.2 (A), K63.2
unnamed: D64.2 (A), K64.2
unnamed: D65.2 (A), K65.1, K65-1.1
unnamed: D69.2 (A), K69.1, K69-1.1
unnamed: D70.2 (A), K70.1
unnamed: D71.2 (A), K71.1
unnamed: D72.2 (A), K72.1
unnamed: D73.2 (A), K73.1
unnamed: D74.2 (A), K74.2
unnamed: D75.2 (A), K75.1
unnamed: D76.2 (A), K76.1
unnamed: D77.2 (A), K77.1
unnamed: D78.2 (A), K78.1
unnamed: D79.2 (A), K79.1
unnamed: D80.2 (A), K80.1
unnamed: D82.2 (A), K82.2
unnamed: D84.2 (A), K84.2
unnamed: D86.2 (A), K86.1
unnamed: D87.2 (A), K87.1
unnamed: D88.2 (A), K88.1
unnamed: D92.2 (A), K92.1
unnamed: D96.2 (A), K96.1
unnamed: D97.2 (A), K97.1
unnamed: D98.2 (A), K98.1
unnamed: D99.2 (A), K99.1
unnamed: D100.2 (A), K100.2
unnamed: D101.2 (A), K101.2
unnamed: D102.2 (A), K102.2
unnamed: L1.1 (K), U1.22 ((XCK1/~CTS~)PD5)
unnamed: L1.2 (A), R1.2
unnamed: R101.1, U1.4 (D+)
unnamed: R101.2, U2.6 (I/O1)
unnamed: R102.1, U1.3 (D-)
unnamed: R102.2, U2.4 (I/O2)
unnamed: R105.2, U1.33 ((~HWB~)PE2)
unnamed: U1.16 (XTAL2), X1.2
unnamed: U1.17 (XTAL1), X1.1
RST: J2.5, R104.1, SW1.2, U1.13 (RESET)
SCK: J2.3, K16.2, K33.2, K50.2, K84.1, K101.1, U1.9 ((SCLK/PCINT1)PB1)
VCC: C103.1, C104.1, C105.1, C106.1, C107.1, F1.1, J2.2, R1.1, R104.2, U1.2 (UVCC), U1.7 (VBUS), U1.14 (VCC), U1.24 (AVCC), U1.34 (VCC), U1.44 (AVCC)
VUSB: F1.2, J1.5, U2.5 (VBUS)
col0: K1.2, K18.2, K35.2, K52.2, K69.2, K69-1.2, K86.2, U1.41 ((ADC0)PF0)
col1: K19.2, K36.1, K53.2, K70.2, K87.2, U1.40 ((ADC1)PF1)
col2: K3.2, K20.2, K37.2, K54.2, K71.2, K88.2, U1.39 ((ADC4/TCK)PF4)
col3: K4.2, K21.2, K38.2, K55.1, K72.2, U1.38 ((ADC5/TMS)PF5)
col4: K5.1, K22.2, K39.2, K56.2, K73.2, U1.37 ((ADC6/TDO)PF6)
col5: K6.2, K23.2, K40.1, K57.2, K74.1, U1.36 ((ADC7/TDI)PF7)
col6: K7.2, K24.2, K41.2, K58.2, K75.2, K92.2, U1.32 ((ICP3/CLK0/OC4A)PC7)
col7: K8.2, K25.2, K42.2, K59.1, K76.2, U1.31 ((OC3A/~OC4A~)PC6)
col8: K9.1, K26.2, K43.2, K60.2, K77.2, U1.30 ((ADC13/OC1B/OC4B/PCINT13)PB6)
col9: K10.2, K27.2, K44.2, K61.2, K78.2, U1.29 ((ADC12/OC1A/~OC4B~/PCINT12)PB5)
col10: K11.2, K28.2, K45.1, K62.2, K79.2, K96.2, U1.28 ((ADC11/PCINT4)PB4)
col11: K12.2, K29.2, K46.2, K63.1, K80.2, K97.2, U1.27 ((T0/OC4D/ADC10)PD7)
col12: K13.1, K30.1, K47.2, K64.1, K98.2, U1.26 ((T1/~OC4D~/ADC9)PD6)
col13: K14.2, K31.2, K48.2, K65.2, K65-1.2, K82.1, K99.2, U1.25 ((ICP2/ADC8)PD4)
col14: K15.1, K32.2, K49.2, K100.1, U1.1 ((INT6/AIN0)PE6)
col16: K17.1, K34.1, K51.1, K102.1, U1.8 ((SS/PCINT0)PB0)
row2: D35.1 (K), D36.1 (K), D37.1 (K), D38.1 (K), D39.1 (K), D40.1 (K), D41.1 (K), D42.1 (K), D43.1 (K), D44.1 (K), D45.1 (K), D46.1 (K), D47.1 (K), D48.1 (K), D49.1 (K), D50.1 (K), D51.1 (K), U1.12 ((OC0A/OC1C/~RTS~/PCINT7)PB7)
row3: D52.1 (K), D53.1 (K), D54.1 (K), D55.1 (K), D56.1 (K), D57.1 (K), D58.1 (K), D59.1 (K), D60.1 (K), D61.1 (K), D62.1 (K), D63.1 (K), D64.1 (K), D65.1 (K), U1.18 ((OC0B/SCL/INT0)PD0)
row4: D69.1 (K), D70.1 (K), D71.1 (K), D72.1 (K), D73.1 (K), D74.1 (K), D75.1 (K), D76.1 (K), D77.1 (K), D78.1 (K), D79.1 (K), D80.1 (K), D82.1 (K), D84.1 (K), U1.19 ((SDA/INT1)PD1)
row5: D86.1 (K), D87.1 (K), D88.1 (K), D92.1 (K), D96.1 (K), D97.1 (K), D98.1 (K), D99.1 (K), D100.1 (K), D101.1 (K), D102.1 (K), U1.20 ((RXD/INT2)PD2)

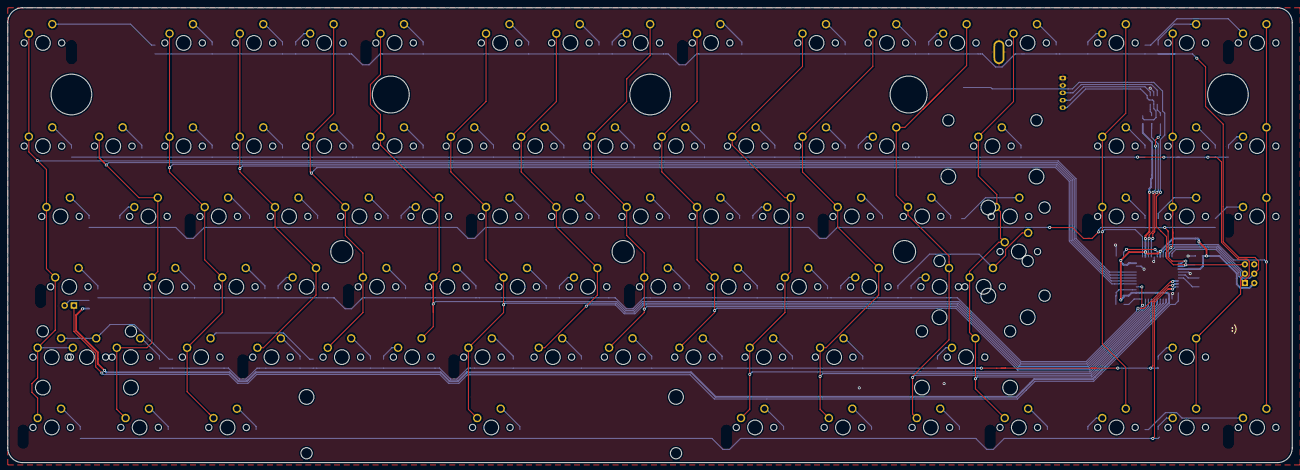
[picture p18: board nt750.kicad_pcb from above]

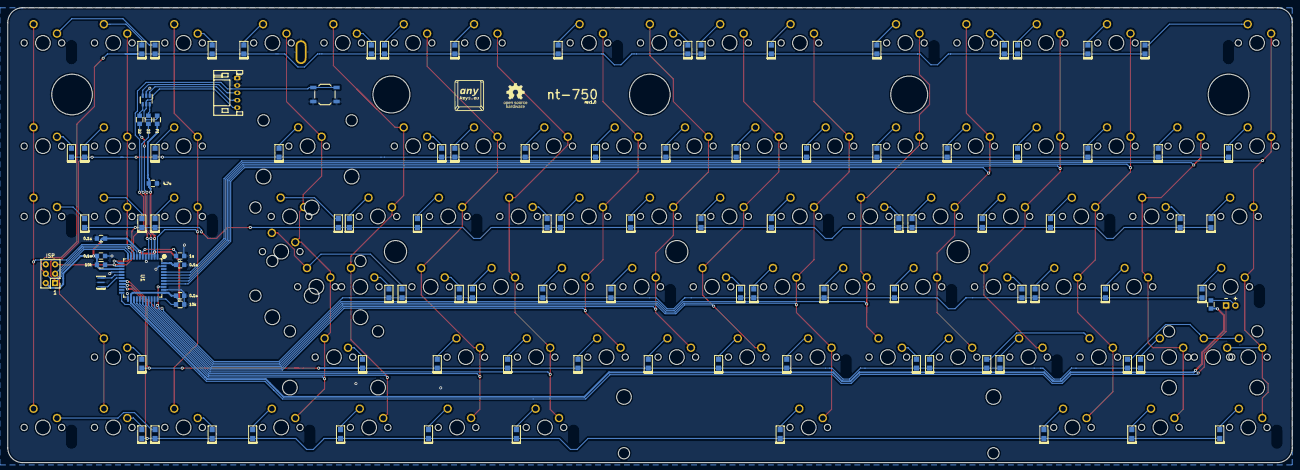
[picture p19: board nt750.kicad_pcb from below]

Board: 2 copper layers, 347.9 x 123.2 mm, 199 parts (107 on the bottom side), 128 nets.

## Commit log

2020-10-06 Upload PCB files
    [nt660.kicad_pcb, nt660.kicad_sch, nt750.kicad_pcb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]
2020-10-25 nt-660 rev1.1
    [nt660.kicad_pcb, nt660.kicad_sch]
2020-10-25 Add PCB images
2020-12-19 Update PCB footprints/gerbers
    [nt660.kicad_pcb, nt660.kicad_sch, nt750.kicad_pcb]
2021-03-21 Add nt660 plate file
    [ansi.dxf, iso.dxf, plate.FCStd]
2022-01-03 Plate Files for FC980m/nt-980 PCBs
    [alternateLayouts.ANSI.dxf, alternateLayouts.ISO.dxf, standardLayout.ANSI.dxf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]
2022-02-01 Upload nt210 files
    [nt210.kicad_pcb, nt210.kicad_sch, pcb-outline.dxf]
2022-06-24 add nt-650
    [nt-650.kicad_pcb, nt-650.kicad_sch]
2022-07-07 Add nt-10
    [nt10.kicad_pcb, nt10.kicad_sch]
